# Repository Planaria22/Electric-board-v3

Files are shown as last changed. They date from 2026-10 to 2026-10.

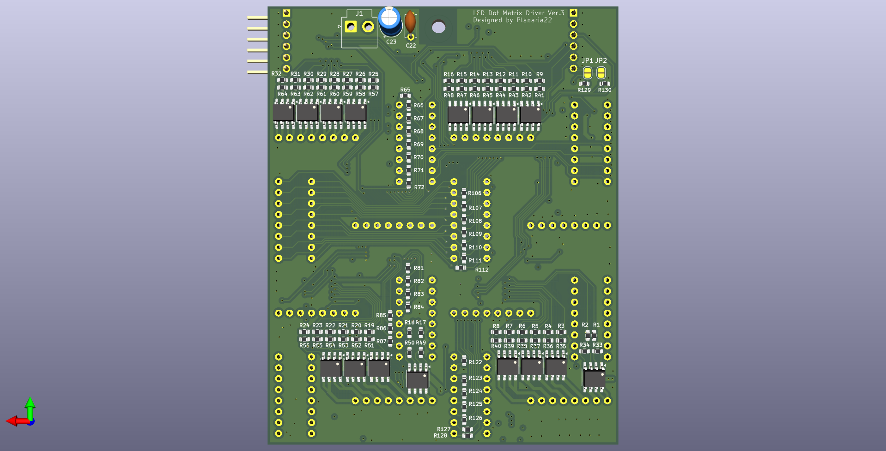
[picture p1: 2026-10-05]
img/dot_matrix_driver/electric_board_driver_v3_bottom.png

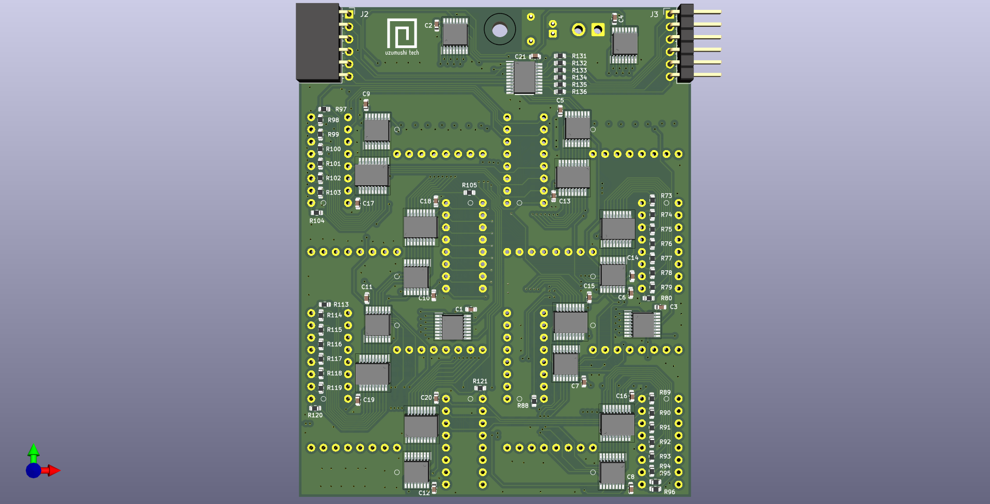
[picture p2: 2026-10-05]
img/dot_matrix_driver/electric_board_driver_v3_front.png

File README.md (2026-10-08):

# Electric-board-v3
2026年高専祭で展示する予定の電光掲示板です

# 概要
- MD1516C2-RG ドットマトリクスLED
  赤色と緑色のアノードコモン2色16×16LEDマトリクス。同時点灯を行うと赤緑橙の3色点灯が可能。このマトリクスをドライバ基板1枚に4個配置し、ドライバ基板を直列につなげることで32×128ドットの電光掲示板を作成する。
- ダイナミック点灯
  電流を流すアノード(行)を変え続けることで使用するピン数と電流を削減する。
- 制御
  カスケード接続された74HC595シフトレジスタを介してSPI通信で制御する。
  ドライバ基板のジャンパを繋げば輝度調整も技術的には可能

# ピンアサイン
ドライバ基板の端子アサイン
## 6pinピンヘッダ・ソケット
```
+---+---+=======+---+---+
| 1 | 2 | 3 | 4 | 5 | 6 |
+---+---+---+---+---+---+
```
※デフォルトでは基板側のOEピンはプルダウンされています。使用する場合はドライバ基板のJP1かJP2、あるいは両方のジャンパを短絡してください。
1. アノードデータ
2. 赤色LEDカソードデータ
3. 緑色LEDカソードデータ
4. 74HC595 シフトレジスタクロック(SRCLK)
5. 74HC595 ストレージレジスタークロック(RCLK)
6. 74HC595 アウトプットエネーブル(OE)

## 電源ピン
```
+=======+
| 1 | 2 |
+---+---+
```
※ドットマトリクス側が下
1. 5V電源+
2. GND電源-

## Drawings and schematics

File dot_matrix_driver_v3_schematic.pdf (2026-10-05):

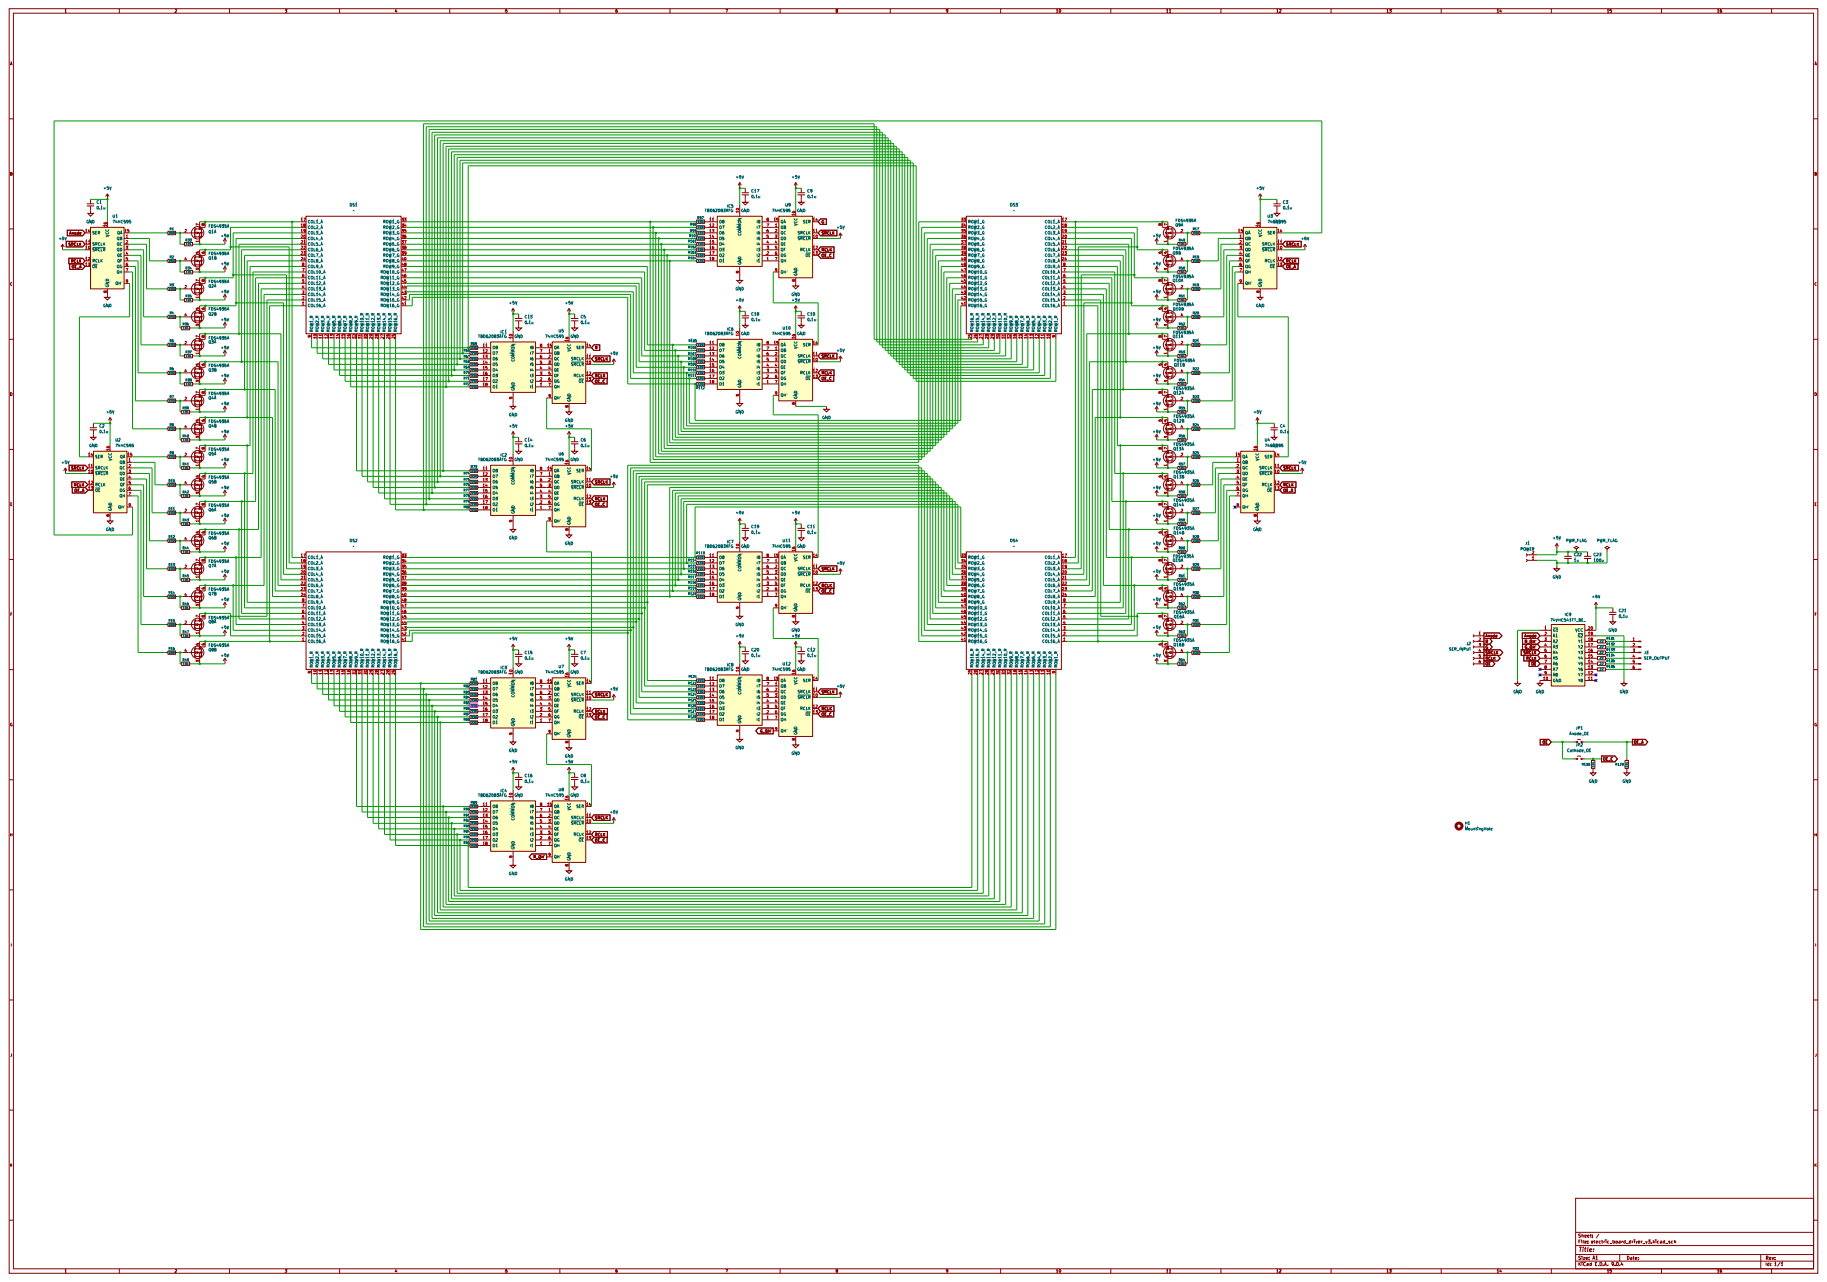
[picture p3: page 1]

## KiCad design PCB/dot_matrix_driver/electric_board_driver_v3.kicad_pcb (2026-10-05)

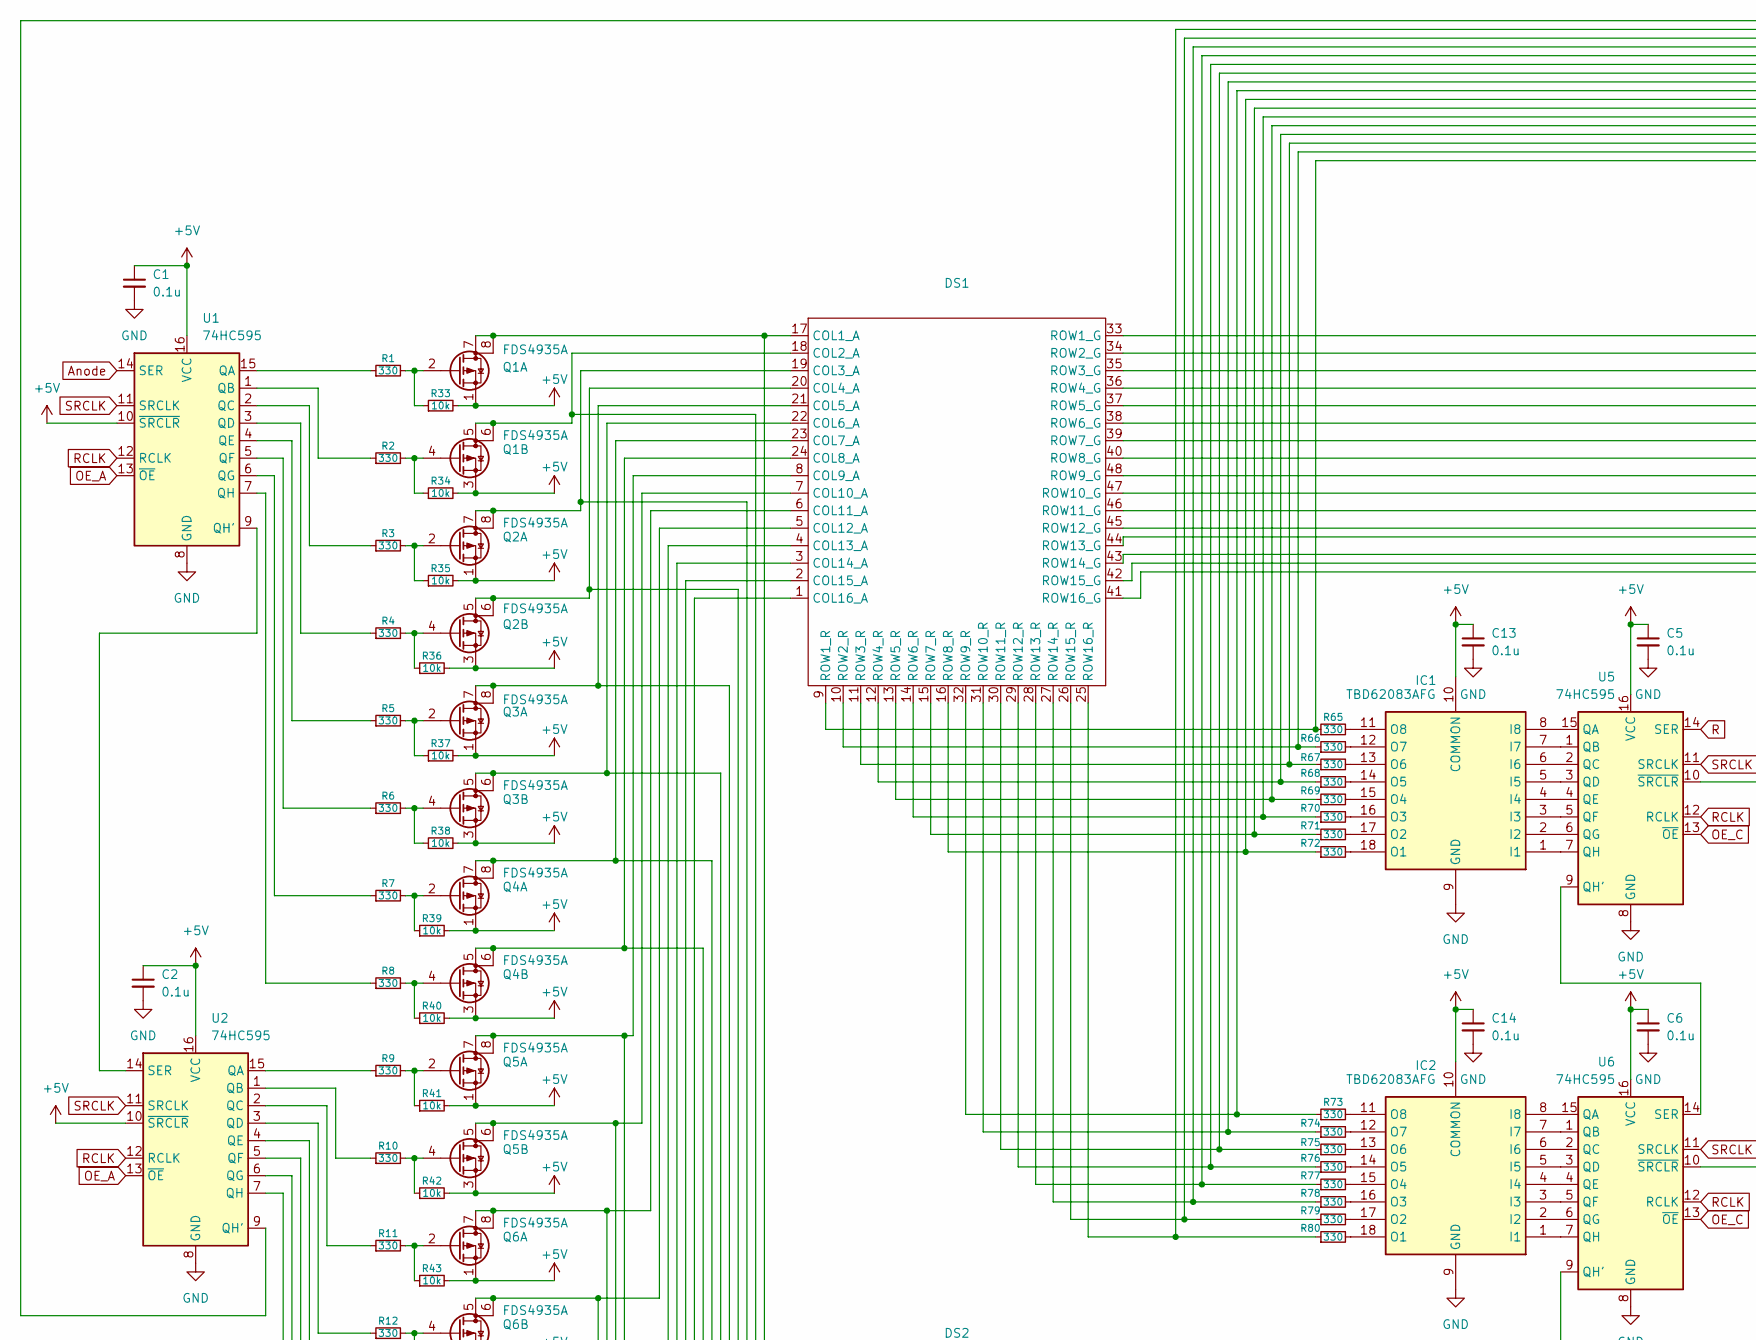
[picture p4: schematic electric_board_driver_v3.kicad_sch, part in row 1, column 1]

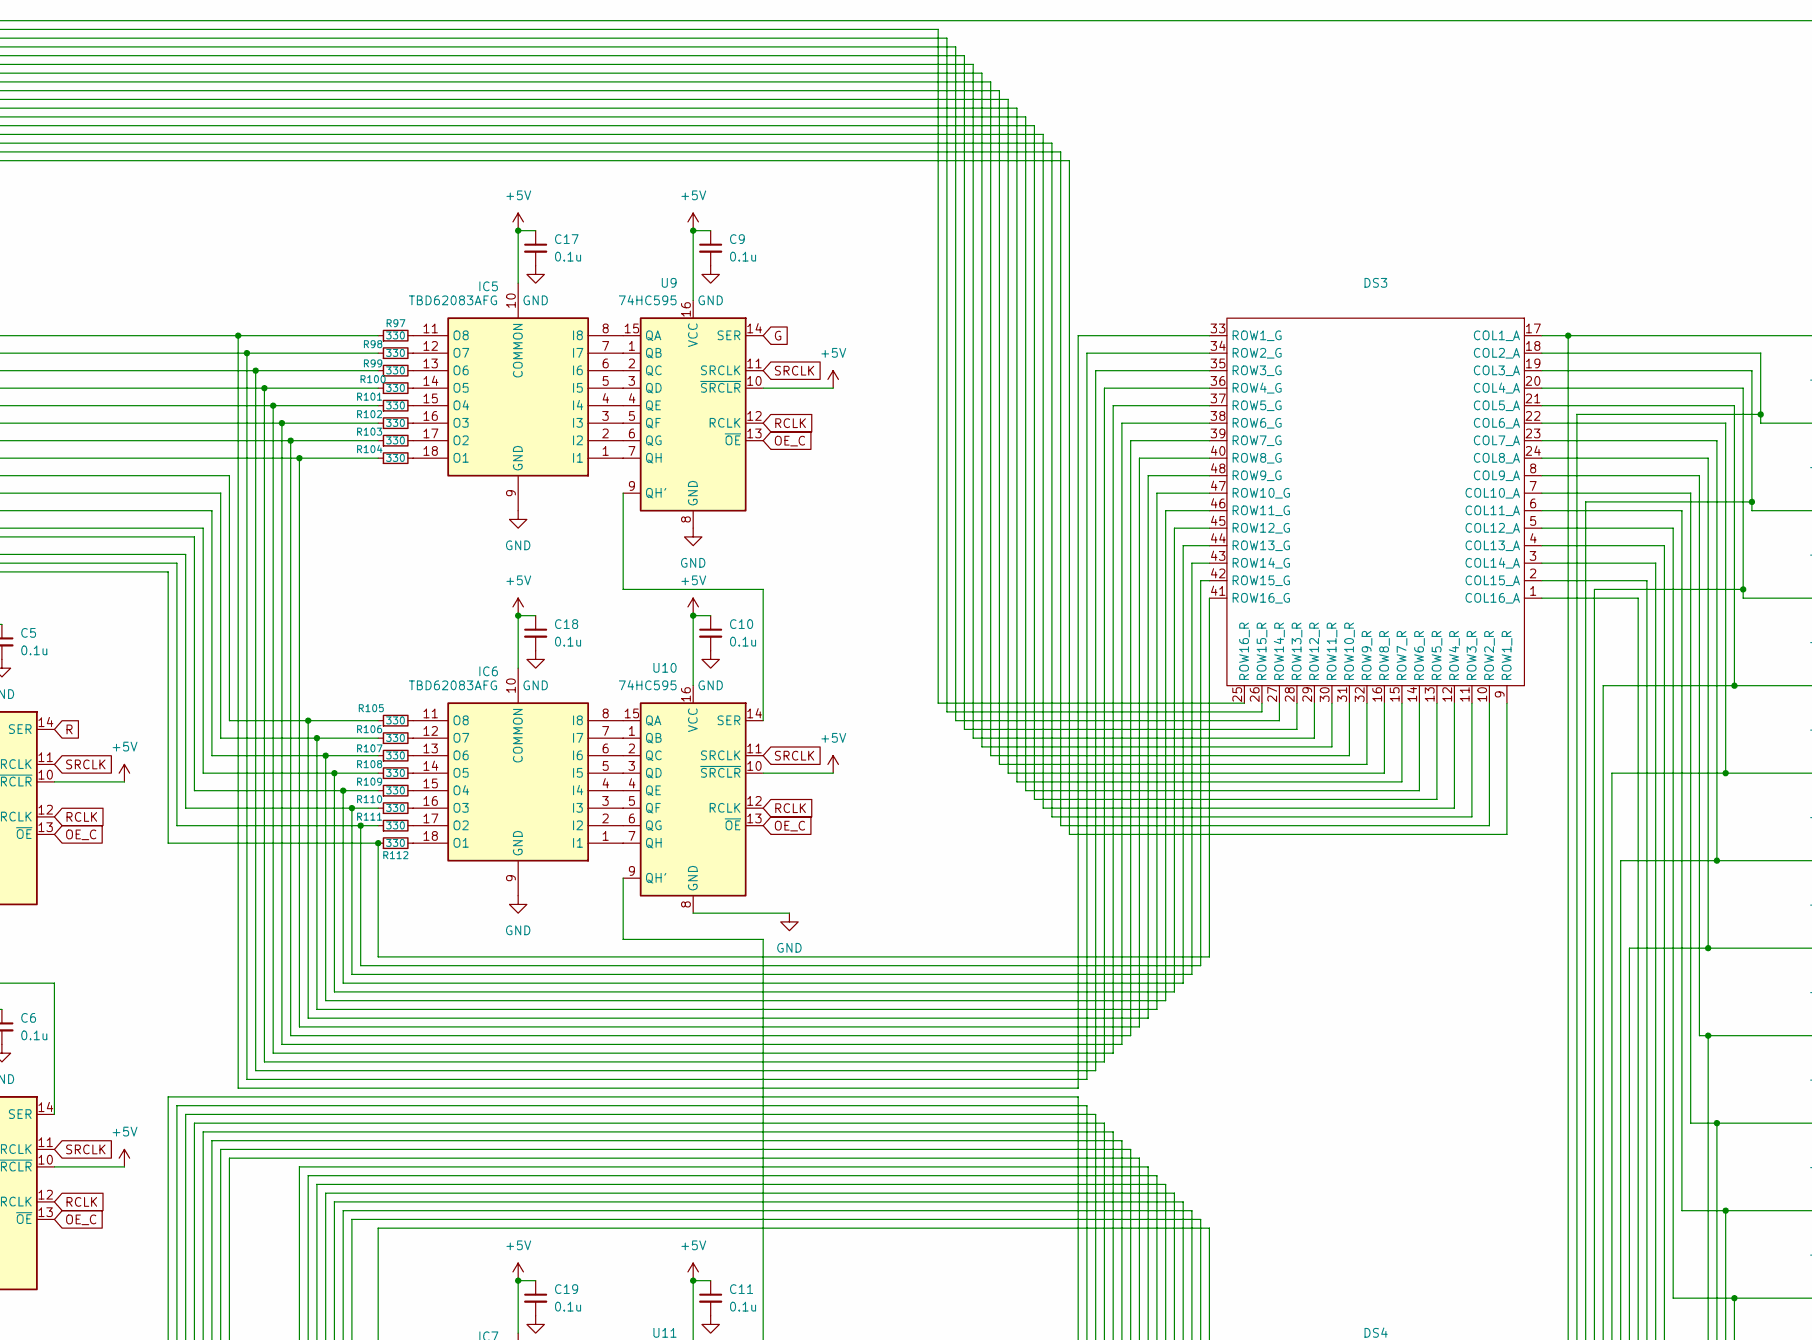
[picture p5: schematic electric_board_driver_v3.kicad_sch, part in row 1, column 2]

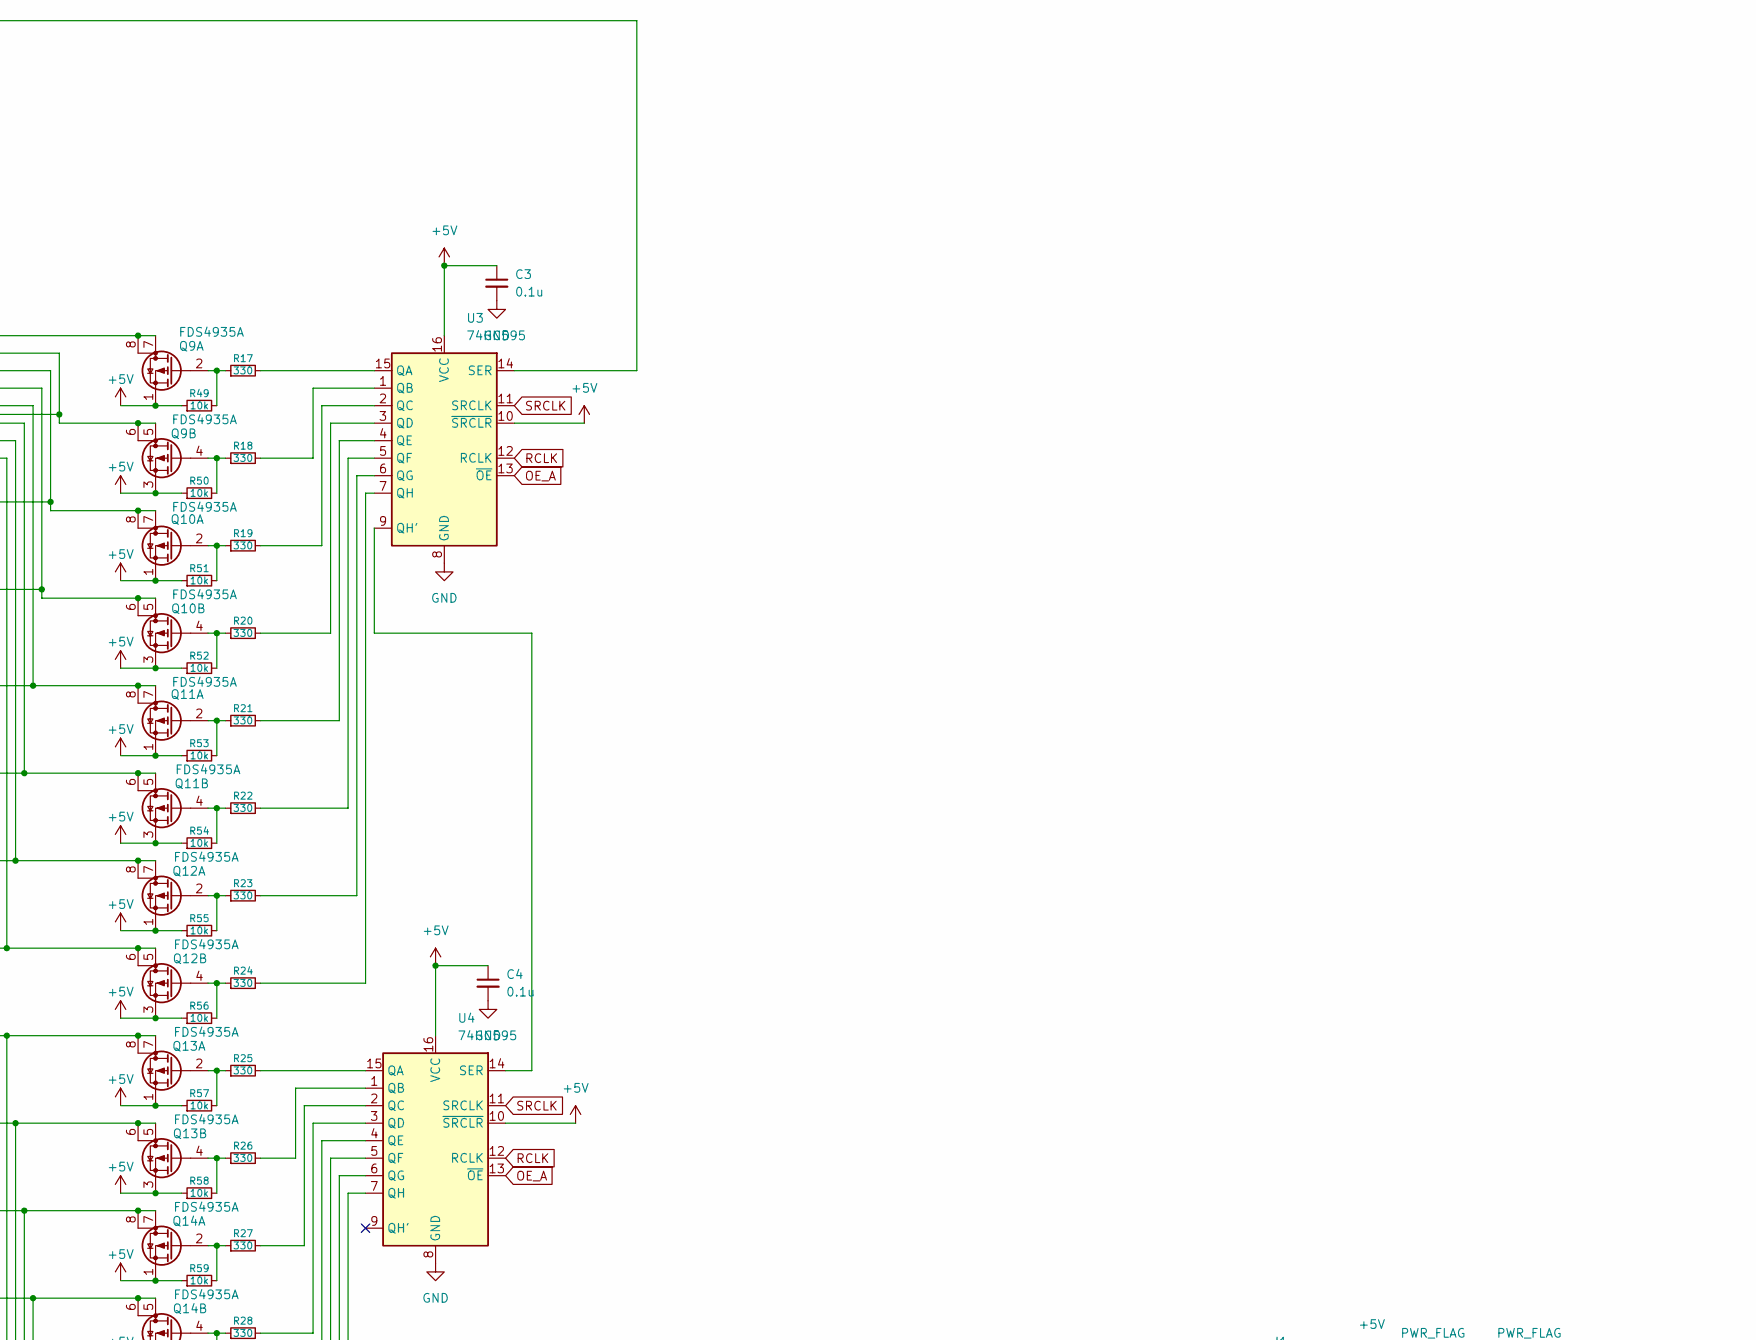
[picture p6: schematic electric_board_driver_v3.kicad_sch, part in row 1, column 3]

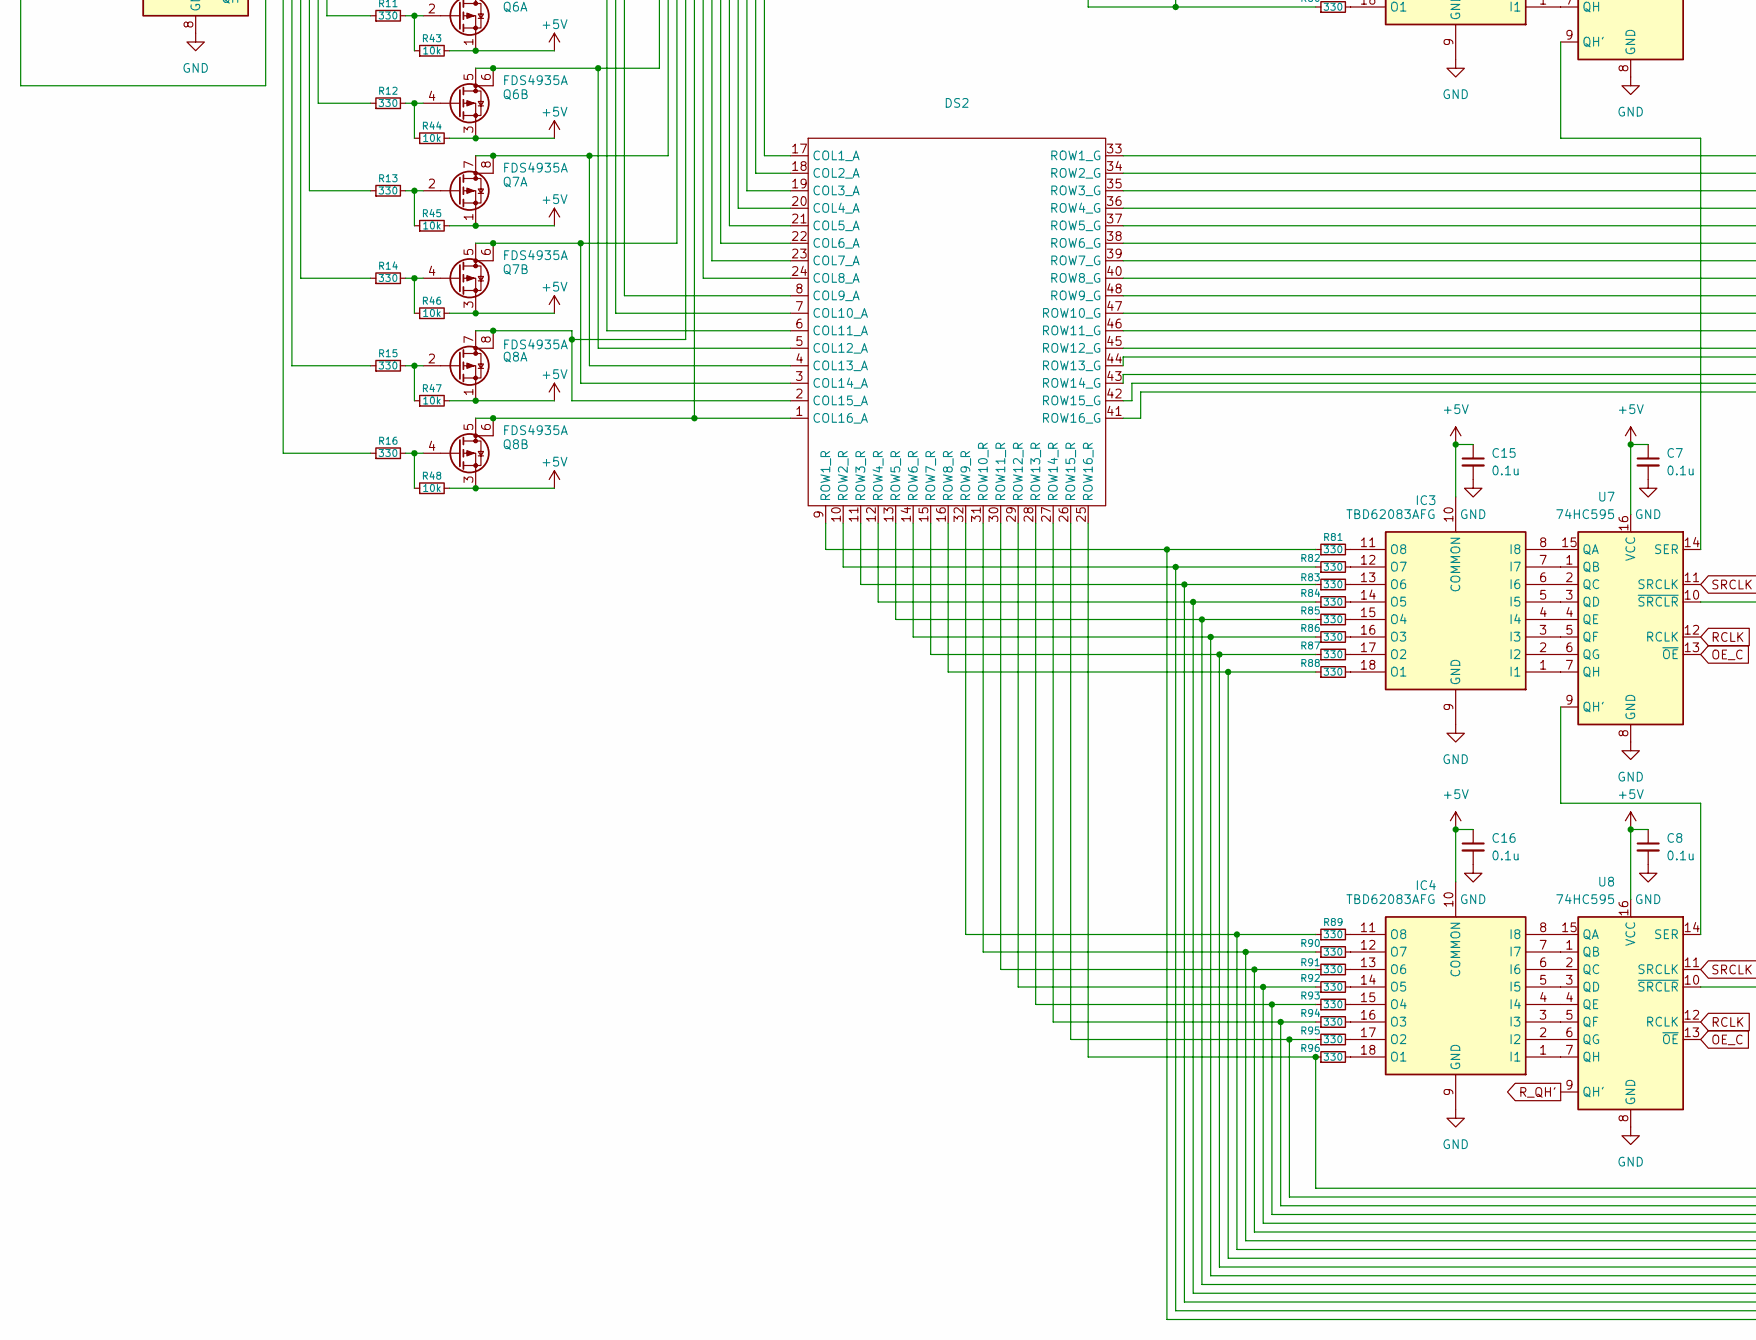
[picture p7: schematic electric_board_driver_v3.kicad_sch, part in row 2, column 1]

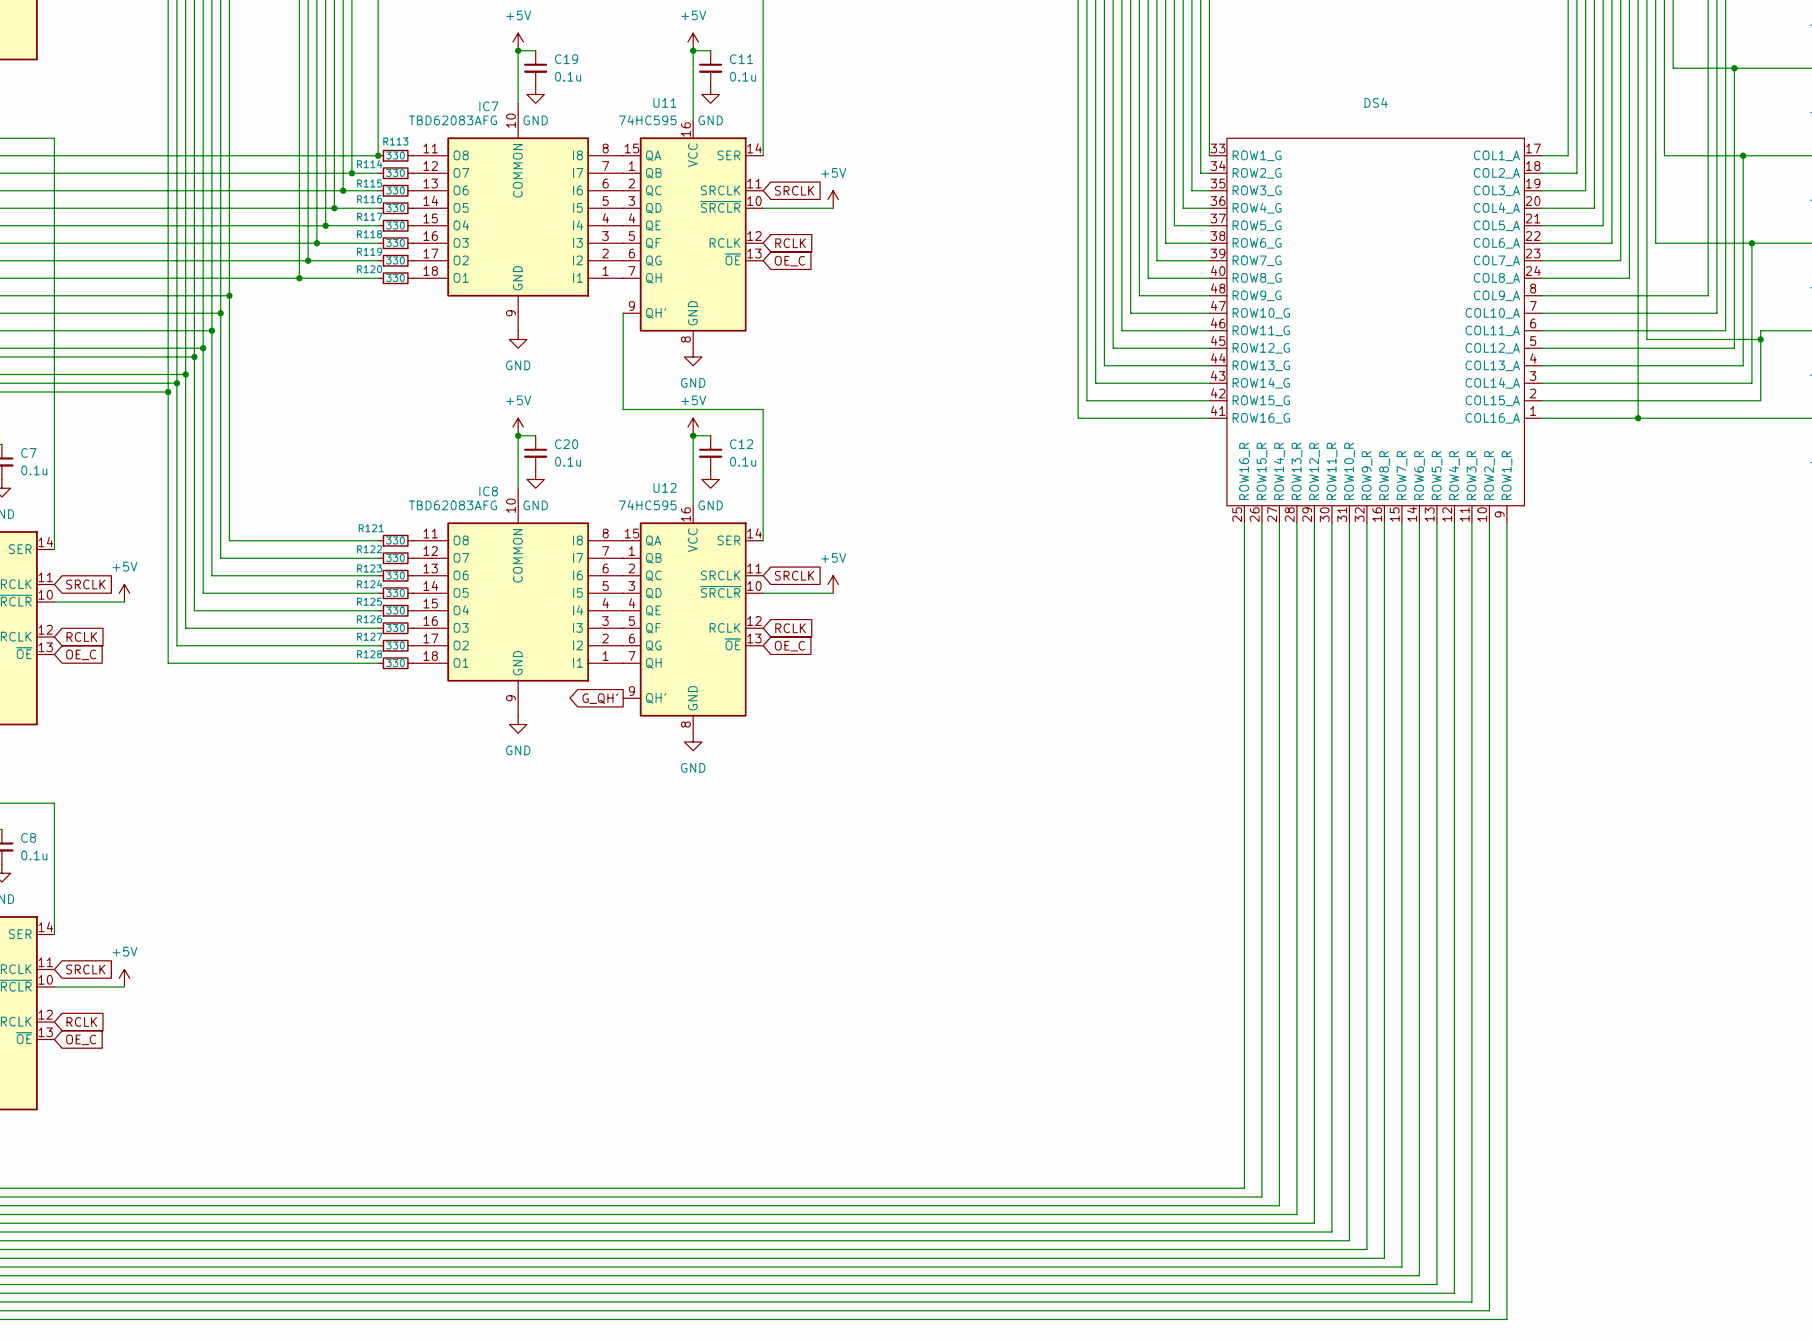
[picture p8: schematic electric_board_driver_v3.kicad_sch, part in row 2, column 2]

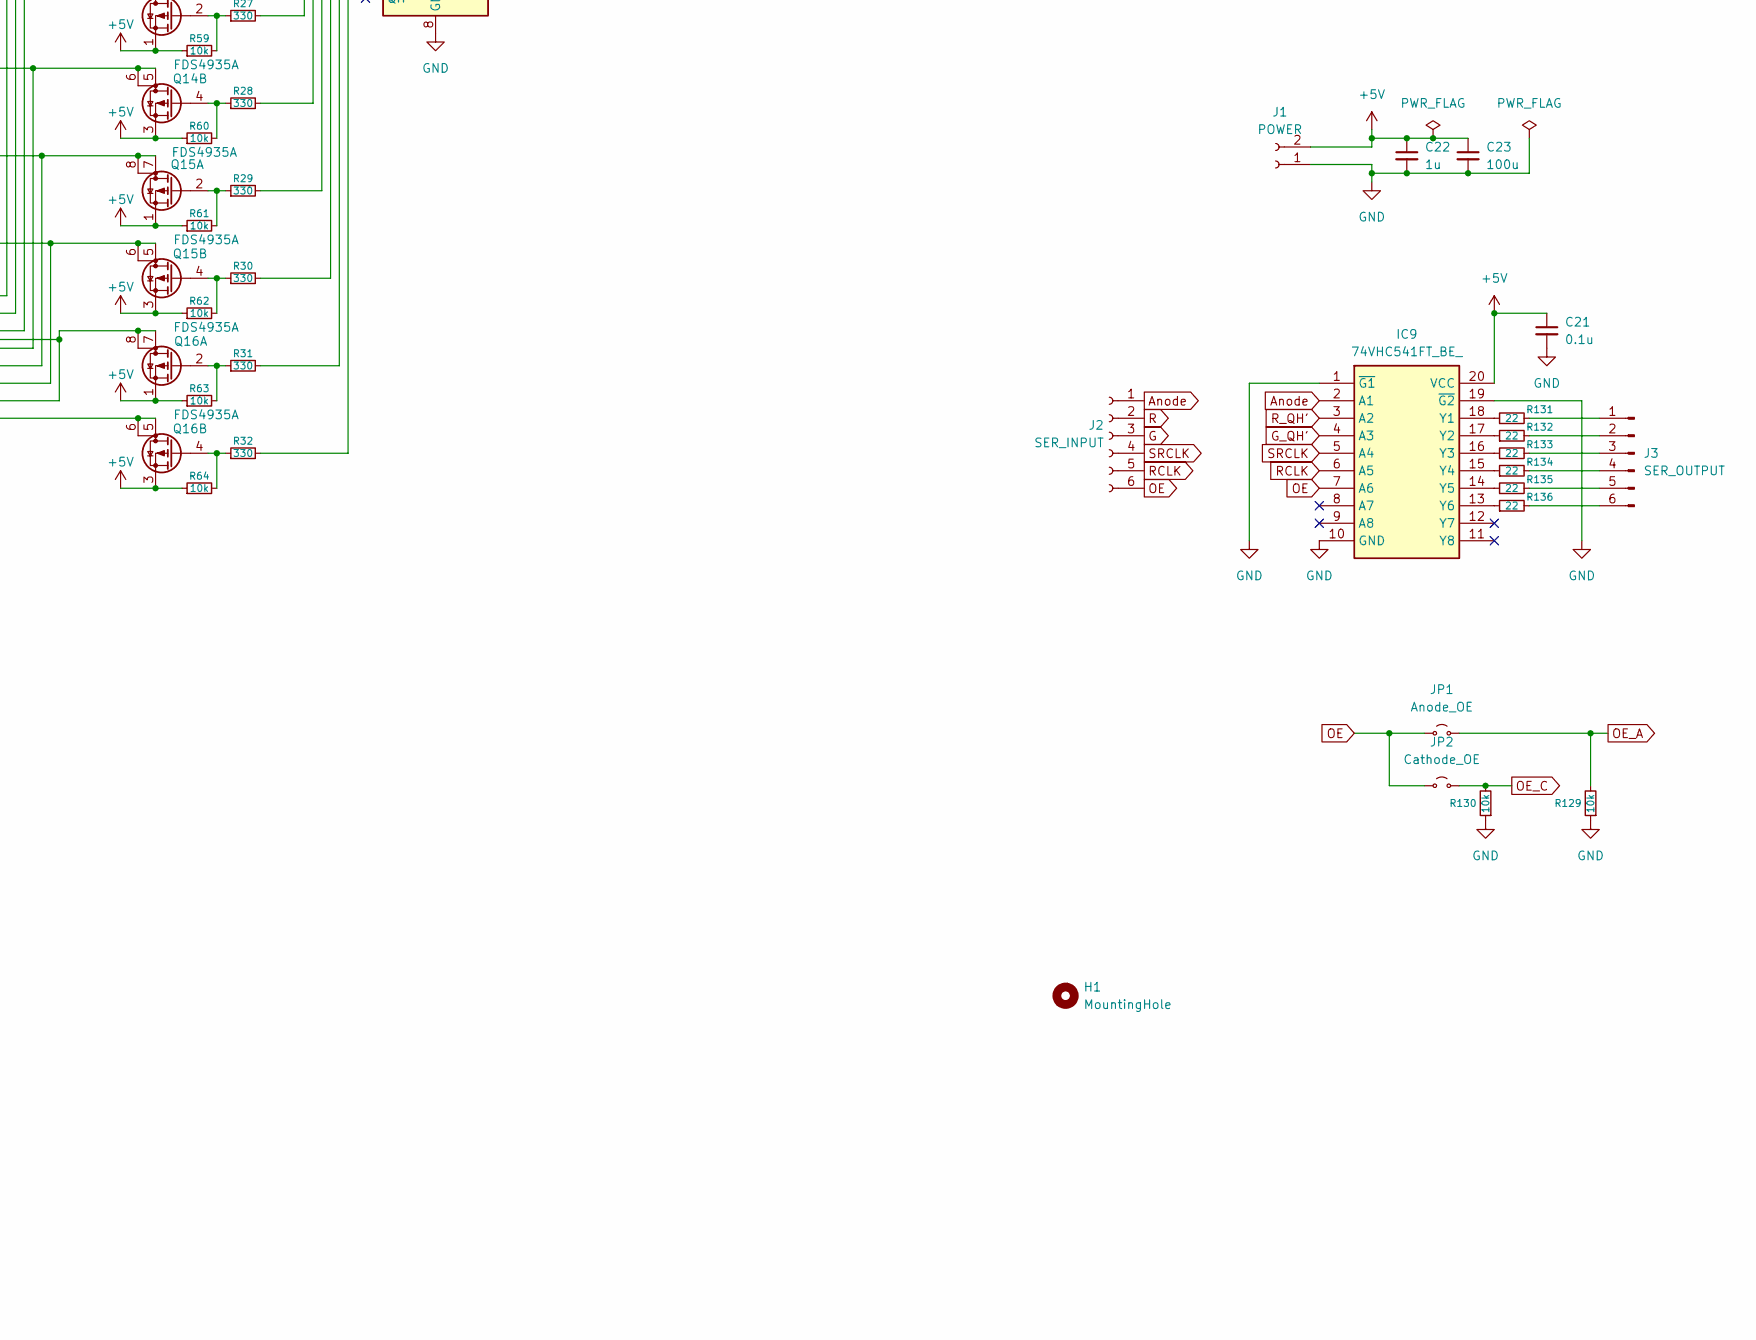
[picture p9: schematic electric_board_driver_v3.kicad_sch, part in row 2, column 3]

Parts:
C1, C2, C3, C4, C5, C6, C7, C8, C9, C10, C11, C12, C13, C14, C15, C16, C17, C18, C19, C20, C21: 0.1u; C_0603_1608Metric
C22: 1u; C_Disc_D5.0mm_W2.5mm_P5.00mm
C23: 100u; CP_Radial_D5.0mm_P2.00mm
DS1, DS2, DS3, DS4: MD1516
H1: MountingHole; MountingHole_3.2mm_M3
IC1, IC2, IC3, IC4, IC5, IC6, IC7, IC8: TBD62083AFG; TBD62083AFNG; Manufacturer_Part_Number TBD62083AFG; Mouser Part Number N/A
IC9: 74VHC541FT_BE_; 74VHC541FT(BE); Manufacturer_Part_Number 74VHC541FT(BE); Mouser Part Number 757-74VHC541FT(BE)
J1: POWER; JST_VH_B2P-VH_1x02_P3.96mm_Vertical
J2: SER_INPUT; PinSocket_1x06_P2.54mm_Horizontal
J3: SER_OUTPUT; PinHeader_1x06_P2.54mm_Horizontal
JP1: Anode_OE; SolderJumper-2_P1.3mm_Open_RoundedPad1.0x1.5mm
JP2: Cathode_OE; SolderJumper-2_P1.3mm_Open_RoundedPad1.0x1.5mm
Q1, Q2, Q3, Q4, Q5, Q6, Q7, Q8, Q9, Q10, Q11, Q12, Q13, Q14, Q15, Q16: FDS4935A; SOIC-8_3.9x4.9mm_P1.27mm
R1, R2, R3, R4, R5, R6, R7, R8, R9, R10, R11, R12, R13, R14, R15, R16, R17, R18, R19, R20, R21, R22, R23, R24, R25, R26, R27, R28, R29, R30, R31, R32, R65, R66, R67, R68, R69, R70, R71, R72, R73, R74, R75, R76, R77, R78, R79, R80, R81, R82, R83, R84, R85, R86, R87, R88, R89, R90, R91, R92, R93, R94, R95, R96, R97, R98, R99, R100, R101, R102, R103, R104, R105, R106, R107, R108, R109, R110, R111, R112, R113, R114, R115, R116, R117, R118, R119, R120, R121, R122, R123, R124, R125, R126, R127, R128: 330; R_0603_1608Metric
R33, R34, R35, R36, R37, R38, R39, R40, R41, R42, R43, R44, R45, R46, R47, R48, R49, R50, R51, R52, R53, R54, R55, R56, R57, R58, R59, R60, R61, R62, R63, R64, R129, R130: 10k; R_0603_1608Metric
R131, R132, R133, R134, R135, R136: 22; R_0603_1608Metric
U1, U2, U3, U4, U5, U6, U7, U8, U9, U10, U11, U12: 74HC595; MC74HC595ADTR2G

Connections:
+5V: C1.1, C2.1, C3.1, C4.1, C5.1, C6.1, C7.1, C8.1, C9.1, C10.1, C11.1, C12.1, C13.1, C14.1, C15.1, C16.1, C17.1, C18.1, C19.1, C20.1, C21.1, C22.1, C23.1, IC1.10 (COMMON), IC2.10 (COMMON), IC3.10 (COMMON), IC4.10 (COMMON), IC5.10 (COMMON), IC6.10 (COMMON), IC7.10 (COMMON), IC8.10 (COMMON), IC9.20 (VCC), J1.2, Q1.1 (S), Q1.3 (S), Q2.1 (S), Q2.3 (S), Q3.1 (S), Q3.3 (S), Q4.1 (S), Q4.3 (S), Q5.1 (S), Q5.3 (S), Q6.1 (S), Q6.3 (S), Q7.1 (S), Q7.3 (S), Q8.1 (S), Q8.3 (S), Q9.1 (S), Q9.3 (S), Q10.1 (S), Q10.3 (S), Q11.1 (S), Q11.3 (S), Q12.1 (S), Q12.3 (S), Q13.1 (S), Q13.3 (S), Q14.1 (S), Q14.3 (S), Q15.1 (S), Q15.3 (S), Q16.1 (S), Q16.3 (S), R33.2, R34.2, R35.2, R36.2, R37.2, R38.2, R39.2, R40.2, R41.2, R42.2, R43.2, R44.2, R45.2, R46.2, R47.2, R48.2, R49.1, R50.1, R51.1, R52.1, R53.1, R54.1, R55.1, R56.1, R57.1, R58.1, R59.1, R60.1, R61.1, R62.1, R63.1, R64.1, U1.10 (~SRCLR), U1.16 (VCC), U2.10 (~SRCLR), U2.16 (VCC), U3.10 (~SRCLR), U3.16 (VCC), U4.10 (~SRCLR), U4.16 (VCC), U5.10 (~SRCLR), U5.16 (VCC), U6.10 (~SRCLR), U6.16 (VCC), U7.10 (~SRCLR), U7.16 (VCC), U8.10 (~SRCLR), U8.16 (VCC), U9.10 (~SRCLR), U9.16 (VCC), U10.10 (~SRCLR), U10.16 (VCC), U11.10 (~SRCLR), U11.16 (VCC), U12.10 (~SRCLR), U12.16 (VCC)
Anode: IC9.2 (A1), J2.1, U1.14 (SER)
G: J2.3, U9.14 (SER)
GND: C1.2, C2.2, C3.2, C4.2, C5.2, C6.2, C7.2, C8.2, C9.2, C10.2, C11.2, C12.2, C13.2, C14.2, C15.2, C16.2, C17.2, C18.2, C19.2, C20.2, C21.2, C22.2, C23.2, IC1.9 (GND), IC2.9 (GND), IC3.9 (GND), IC4.9 (GND), IC5.9 (GND), IC6.9 (GND), IC7.9 (GND), IC8.9 (GND), IC9.1 (~G1), IC9.10 (GND), IC9.19 (~G2), J1.1, R129.1, R130.1, U1.8 (GND), U2.8 (GND), U3.8 (GND), U4.8 (GND), U5.8 (GND), U6.8 (GND), U7.8 (GND), U8.8 (GND), U9.8 (GND), U10.8 (GND), U11.8 (GND), U12.8 (GND)
G_QH': IC9.4 (A3), U12.9 (QH')
unnamed: DS1.17 (COL1_A), DS2.17 (COL1_A), Q1.7 (D), Q1.8 (D)
unnamed: DS1.18 (COL2_A), DS2.18 (COL2_A), Q1.5 (D), Q1.6 (D)
unnamed: DS1.19 (COL3_A), DS2.19 (COL3_A), Q2.7 (D), Q2.8 (D)
unnamed: DS1.20 (COL4_A), DS2.20 (COL4_A), Q2.5 (D), Q2.6 (D)
unnamed: DS1.21 (COL5_A), DS2.21 (COL5_A), Q3.7 (D), Q3.8 (D)
unnamed: DS1.22 (COL6_A), DS2.22 (COL6_A), Q3.5 (D), Q3.6 (D)
unnamed: DS1.23 (COL7_A), DS2.23 (COL7_A), Q4.7 (D), Q4.8 (D)
unnamed: DS1.24 (COL8_A), DS2.24 (COL8_A), Q4.5 (D), Q4.6 (D)
unnamed: DS1.8 (COL9_A), DS2.8 (COL9_A), Q5.7 (D), Q5.8 (D)
unnamed: DS1.7 (COL10_A), DS2.7 (COL10_A), Q5.5 (D), Q5.6 (D)
unnamed: DS1.6 (COL11_A), DS2.6 (COL11_A), Q6.7 (D), Q6.8 (D)
unnamed: DS1.5 (COL12_A), DS2.5 (COL12_A), Q6.5 (D), Q6.6 (D)
unnamed: DS1.4 (COL13_A), DS2.4 (COL13_A), Q7.7 (D), Q7.8 (D)
unnamed: DS1.3 (COL14_A), DS2.3 (COL14_A), Q7.5 (D), Q7.6 (D)
unnamed: DS1.2 (COL15_A), DS2.2 (COL15_A), Q8.7 (D), Q8.8 (D)
unnamed: DS1.1 (COL16_A), DS2.1 (COL16_A), Q8.5 (D), Q8.6 (D)
unnamed: DS1.33 (ROW1_G), DS3.33 (ROW1_G), R97.1
unnamed: DS1.9 (ROW1_R), DS3.9 (ROW1_R), R65.1
unnamed: DS1.34 (ROW2_G), DS3.34 (ROW2_G), R98.1
unnamed: DS1.10 (ROW2_R), DS3.10 (ROW2_R), R66.1
unnamed: DS1.35 (ROW3_G), DS3.35 (ROW3_G), R99.1
unnamed: DS1.11 (ROW3_R), DS3.11 (ROW3_R), R67.1
unnamed: DS1.36 (ROW4_G), DS3.36 (ROW4_G), R100.1
unnamed: DS1.12 (ROW4_R), DS3.12 (ROW4_R), R68.1
unnamed: DS1.37 (ROW5_G), DS3.37 (ROW5_G), R101.1
unnamed: DS1.13 (ROW5_R), DS3.13 (ROW5_R), R69.1
unnamed: DS1.38 (ROW6_G), DS3.38 (ROW6_G), R102.1
unnamed: DS1.14 (ROW6_R), DS3.14 (ROW6_R), R70.1
unnamed: DS1.39 (ROW7_G), DS3.39 (ROW7_G), R103.1
unnamed: DS1.15 (ROW7_R), DS3.15 (ROW7_R), R71.1
unnamed: DS1.40 (ROW8_G), DS3.40 (ROW8_G), R104.1
unnamed: DS1.16 (ROW8_R), DS3.16 (ROW8_R), R72.1
unnamed: DS1.48 (ROW9_G), DS3.48 (ROW9_G), R105.1
unnamed: DS1.32 (ROW9_R), DS3.32 (ROW9_R), R73.1
unnamed: DS1.47 (ROW10_G), DS3.47 (ROW10_G), R106.1
unnamed: DS1.31 (ROW10_R), DS3.31 (ROW10_R), R74.1
unnamed: DS1.46 (ROW11_G), DS3.46 (ROW11_G), R107.1
unnamed: DS1.30 (ROW11_R), DS3.30 (ROW11_R), R75.1
unnamed: DS1.45 (ROW12_G), DS3.45 (ROW12_G), R108.1
unnamed: DS1.29 (ROW12_R), DS3.29 (ROW12_R), R76.1
unnamed: DS1.44 (ROW13_G), DS3.44 (ROW13_G), R109.1
unnamed: DS1.28 (ROW13_R), DS3.28 (ROW13_R), R77.1
unnamed: DS1.43 (ROW14_G), DS3.43 (ROW14_G), R110.1
unnamed: DS1.27 (ROW14_R), DS3.27 (ROW14_R), R78.1
unnamed: DS1.42 (ROW15_G), DS3.42 (ROW15_G), R111.1
unnamed: DS1.26 (ROW15_R), DS3.26 (ROW15_R), R79.1
unnamed: DS1.41 (ROW16_G), DS3.41 (ROW16_G), R112.1
unnamed: DS1.25 (ROW16_R), DS3.25 (ROW16_R), R80.1
unnamed: DS2.33 (ROW1_G), DS4.33 (ROW1_G), R113.1
unnamed: DS2.9 (ROW1_R), DS4.9 (ROW1_R), R81.1
unnamed: DS2.34 (ROW2_G), DS4.34 (ROW2_G), R114.1
unnamed: DS2.10 (ROW2_R), DS4.10 (ROW2_R), R82.1
unnamed: DS2.35 (ROW3_G), DS4.35 (ROW3_G), R115.1
unnamed: DS2.11 (ROW3_R), DS4.11 (ROW3_R), R83.1
unnamed: DS2.36 (ROW4_G), DS4.36 (ROW4_G), R116.1
unnamed: DS2.12 (ROW4_R), DS4.12 (ROW4_R), R84.1
unnamed: DS2.37 (ROW5_G), DS4.37 (ROW5_G), R117.1
unnamed: DS2.13 (ROW5_R), DS4.13 (ROW5_R), R85.1
unnamed: DS2.38 (ROW6_G), DS4.38 (ROW6_G), R118.1
unnamed: DS2.14 (ROW6_R), DS4.14 (ROW6_R), R86.1
unnamed: DS2.39 (ROW7_G), DS4.39 (ROW7_G), R119.1
unnamed: DS2.15 (ROW7_R), DS4.15 (ROW7_R), R87.1
unnamed: DS2.40 (ROW8_G), DS4.40 (ROW8_G), R120.1
unnamed: DS2.16 (ROW8_R), DS4.16 (ROW8_R), R88.1
unnamed: DS2.48 (ROW9_G), DS4.48 (ROW9_G), R121.1
unnamed: DS2.32 (ROW9_R), DS4.32 (ROW9_R), R89.1
unnamed: DS2.47 (ROW10_G), DS4.47 (ROW10_G), R122.1
unnamed: DS2.31 (ROW10_R), DS4.31 (ROW10_R), R90.1
unnamed: DS2.46 (ROW11_G), DS4.46 (ROW11_G), R123.1
unnamed: DS2.30 (ROW11_R), DS4.30 (ROW11_R), R91.1
unnamed: DS2.45 (ROW12_G), DS4.45 (ROW12_G), R124.1
unnamed: DS2.29 (ROW12_R), DS4.29 (ROW12_R), R92.1
unnamed: DS2.44 (ROW13_G), DS4.44 (ROW13_G), R125.1
unnamed: DS2.28 (ROW13_R), DS4.28 (ROW13_R), R93.1
unnamed: DS2.43 (ROW14_G), DS4.43 (ROW14_G), R126.1
unnamed: DS2.27 (ROW14_R), DS4.27 (ROW14_R), R94.1
unnamed: DS2.42 (ROW15_G), DS4.42 (ROW15_G), R127.1
unnamed: DS2.26 (ROW15_R), DS4.26 (ROW15_R), R95.1
unnamed: DS2.41 (ROW16_G), DS4.41 (ROW16_G), R128.1
unnamed: DS2.25 (ROW16_R), DS4.25 (ROW16_R), R96.1
unnamed: DS3.17 (COL1_A), DS4.17 (COL1_A), Q9.7 (D), Q9.8 (D)
unnamed: DS3.18 (COL2_A), DS4.18 (COL2_A), Q9.5 (D), Q9.6 (D)
unnamed: DS3.19 (COL3_A), DS4.19 (COL3_A), Q10.7 (D), Q10.8 (D)
unnamed: DS3.20 (COL4_A), DS4.20 (COL4_A), Q10.5 (D), Q10.6 (D)
unnamed: DS3.21 (COL5_A), DS4.21 (COL5_A), Q11.7 (D), Q11.8 (D)
unnamed: DS3.22 (COL6_A), DS4.22 (COL6_A), Q11.5 (D), Q11.6 (D)
unnamed: DS3.23 (COL7_A), DS4.23 (COL7_A), Q12.7 (D), Q12.8 (D)
unnamed: DS3.24 (COL8_A), DS4.24 (COL8_A), Q12.5 (D), Q12.6 (D)
unnamed: DS3.8 (COL9_A), DS4.8 (COL9_A), Q13.7 (D), Q13.8 (D)
unnamed: DS3.7 (COL10_A), DS4.7 (COL10_A), Q13.5 (D), Q13.6 (D)
unnamed: DS3.6 (COL11_A), DS4.6 (COL11_A), Q14.7 (D), Q14.8 (D)
unnamed: DS3.5 (COL12_A), DS4.5 (COL12_A), Q14.5 (D), Q14.6 (D)
unnamed: DS3.4 (COL13_A), DS4.4 (COL13_A), Q15.7 (D), Q15.8 (D)
unnamed: DS3.3 (COL14_A), DS4.3 (COL14_A), Q15.5 (D), Q15.6 (D)
unnamed: DS3.2 (COL15_A), DS4.2 (COL15_A), Q16.7 (D), Q16.8 (D)
unnamed: DS3.1 (COL16_A), DS4.1 (COL16_A), Q16.5 (D), Q16.6 (D)
unnamed: IC1.1 (I1), U5.7 (QH)
unnamed: IC1.2 (I2), U5.6 (QG)
unnamed: IC1.3 (I3), U5.5 (QF)
unnamed: IC1.4 (I4), U5.4 (QE)
unnamed: IC1.5 (I5), U5.3 (QD)
unnamed: IC1.6 (I6), U5.2 (QC)
unnamed: IC1.7 (I7), U5.1 (QB)
unnamed: IC1.8 (I8), U5.15 (QA)
unnamed: IC1.18 (O1), R72.2
unnamed: IC1.17 (O2), R71.2
unnamed: IC1.16 (O3), R70.2
unnamed: IC1.15 (O4), R69.2
unnamed: IC1.14 (O5), R68.2
unnamed: IC1.13 (O6), R67.2
unnamed: IC1.12 (O7), R66.2
unnamed: IC1.11 (O8), R65.2
unnamed: IC2.1 (I1), U6.7 (QH)
unnamed: IC2.2 (I2), U6.6 (QG)
unnamed: IC2.3 (I3), U6.5 (QF)
unnamed: IC2.4 (I4), U6.4 (QE)
unnamed: IC2.5 (I5), U6.3 (QD)
unnamed: IC2.6 (I6), U6.2 (QC)
unnamed: IC2.7 (I7), U6.1 (QB)
unnamed: IC2.8 (I8), U6.15 (QA)
unnamed: IC2.18 (O1), R80.2
unnamed: IC2.17 (O2), R79.2
unnamed: IC2.16 (O3), R78.2
unnamed: IC2.15 (O4), R77.2
unnamed: IC2.14 (O5), R76.2
unnamed: IC2.13 (O6), R75.2
unnamed: IC2.12 (O7), R74.2
unnamed: IC2.11 (O8), R73.2
unnamed: IC3.1 (I1), U7.7 (QH)
unnamed: IC3.2 (I2), U7.6 (QG)
unnamed: IC3.3 (I3), U7.5 (QF)
unnamed: IC3.4 (I4), U7.4 (QE)
unnamed: IC3.5 (I5), U7.3 (QD)
unnamed: IC3.6 (I6), U7.2 (QC)
unnamed: IC3.7 (I7), U7.1 (QB)
unnamed: IC3.8 (I8), U7.15 (QA)
unnamed: IC3.18 (O1), R88.2
unnamed: IC3.17 (O2), R87.2
unnamed: IC3.16 (O3), R86.2
unnamed: IC3.15 (O4), R85.2
unnamed: IC3.14 (O5), R84.2
unnamed: IC3.13 (O6), R83.2
unnamed: IC3.12 (O7), R82.2
unnamed: IC3.11 (O8), R81.2
unnamed: IC4.1 (I1), U8.7 (QH)
unnamed: IC4.2 (I2), U8.6 (QG)
unnamed: IC4.3 (I3), U8.5 (QF)
unnamed: IC4.4 (I4), U8.4 (QE)
unnamed: IC4.5 (I5), U8.3 (QD)
unnamed: IC4.6 (I6), U8.2 (QC)
unnamed: IC4.7 (I7), U8.1 (QB)
unnamed: IC4.8 (I8), U8.15 (QA)
unnamed: IC4.18 (O1), R96.2
unnamed: IC4.17 (O2), R95.2
unnamed: IC4.16 (O3), R94.2
unnamed: IC4.15 (O4), R93.2
unnamed: IC4.14 (O5), R92.2
unnamed: IC4.13 (O6), R91.2
unnamed: IC4.12 (O7), R90.2
unnamed: IC4.11 (O8), R89.2
unnamed: IC5.1 (I1), U9.7 (QH)
unnamed: IC5.2 (I2), U9.6 (QG)
unnamed: IC5.3 (I3), U9.5 (QF)
unnamed: IC5.4 (I4), U9.4 (QE)
unnamed: IC5.5 (I5), U9.3 (QD)
unnamed: IC5.6 (I6), U9.2 (QC)
unnamed: IC5.7 (I7), U9.1 (QB)
unnamed: IC5.8 (I8), U9.15 (QA)
unnamed: IC5.18 (O1), R104.2
unnamed: IC5.17 (O2), R103.2
unnamed: IC5.16 (O3), R102.2
unnamed: IC5.15 (O4), R101.2
unnamed: IC5.14 (O5), R100.2
unnamed: IC5.13 (O6), R99.2
unnamed: IC5.12 (O7), R98.2
unnamed: IC5.11 (O8), R97.2
unnamed: IC6.1 (I1), U10.7 (QH)
unnamed: IC6.2 (I2), U10.6 (QG)
unnamed: IC6.3 (I3), U10.5 (QF)
unnamed: IC6.4 (I4), U10.4 (QE)
unnamed: IC6.5 (I5), U10.3 (QD)
unnamed: IC6.6 (I6), U10.2 (QC)
unnamed: IC6.7 (I7), U10.1 (QB)
unnamed: IC6.8 (I8), U10.15 (QA)
unnamed: IC6.18 (O1), R112.2
unnamed: IC6.17 (O2), R111.2
unnamed: IC6.16 (O3), R110.2
unnamed: IC6.15 (O4), R109.2
unnamed: IC6.14 (O5), R108.2
unnamed: IC6.13 (O6), R107.2
unnamed: IC6.12 (O7), R106.2
unnamed: IC6.11 (O8), R105.2
unnamed: IC7.1 (I1), U11.7 (QH)
unnamed: IC7.2 (I2), U11.6 (QG)
unnamed: IC7.3 (I3), U11.5 (QF)
unnamed: IC7.4 (I4), U11.4 (QE)
unnamed: IC7.5 (I5), U11.3 (QD)
unnamed: IC7.6 (I6), U11.2 (QC)
unnamed: IC7.7 (I7), U11.1 (QB)
unnamed: IC7.8 (I8), U11.15 (QA)
unnamed: IC7.18 (O1), R120.2
unnamed: IC7.17 (O2), R119.2
unnamed: IC7.16 (O3), R118.2
unnamed: IC7.15 (O4), R117.2
unnamed: IC7.14 (O5), R116.2
unnamed: IC7.13 (O6), R115.2
unnamed: IC7.12 (O7), R114.2
unnamed: IC7.11 (O8), R113.2
unnamed: IC8.1 (I1), U12.7 (QH)
unnamed: IC8.2 (I2), U12.6 (QG)
unnamed: IC8.3 (I3), U12.5 (QF)
unnamed: IC8.4 (I4), U12.4 (QE)
unnamed: IC8.5 (I5), U12.3 (QD)
unnamed: IC8.6 (I6), U12.2 (QC)
unnamed: IC8.7 (I7), U12.1 (QB)
unnamed: IC8.8 (I8), U12.15 (QA)
unnamed: IC8.18 (O1), R128.2
unnamed: IC8.17 (O2), R127.2
unnamed: IC8.16 (O3), R126.2
unnamed: IC8.15 (O4), R125.2
unnamed: IC8.14 (O5), R124.2
unnamed: IC8.13 (O6), R123.2
unnamed: IC8.12 (O7), R122.2
unnamed: IC8.11 (O8), R121.2
unnamed: IC9.18 (Y1), R131.1
unnamed: IC9.17 (Y2), R132.1
unnamed: IC9.16 (Y3), R133.1
unnamed: IC9.15 (Y4), R134.1
unnamed: IC9.14 (Y5), R135.1
unnamed: IC9.13 (Y6), R136.1
unnamed: J3.1, R131.2
unnamed: J3.2, R132.2
unnamed: J3.3, R133.2
unnamed: J3.4, R134.2
unnamed: J3.5, R135.2
unnamed: J3.6, R136.2
unnamed: Q1.2 (G), R1.2, R33.1
unnamed: Q1.4 (G), R2.2, R34.1
unnamed: Q2.2 (G), R3.2, R35.1
unnamed: Q2.4 (G), R4.2, R36.1
unnamed: Q3.2 (G), R5.2, R37.1
unnamed: Q3.4 (G), R6.2, R38.1
unnamed: Q4.2 (G), R7.2, R39.1
unnamed: Q4.4 (G), R8.2, R40.1
unnamed: Q5.2 (G), R9.2, R41.1
unnamed: Q5.4 (G), R10.2, R42.1
unnamed: Q6.2 (G), R11.2, R43.1
unnamed: Q6.4 (G), R12.2, R44.1
unnamed: Q7.2 (G), R13.2, R45.1
unnamed: Q7.4 (G), R14.2, R46.1
unnamed: Q8.2 (G), R15.2, R47.1
unnamed: Q8.4 (G), R16.2, R48.1
unnamed: Q9.2 (G), R17.1, R49.2
unnamed: Q9.4 (G), R18.1, R50.2
unnamed: Q10.2 (G), R19.1, R51.2
unnamed: Q10.4 (G), R20.1, R52.2
unnamed: Q11.2 (G), R21.1, R53.2
unnamed: Q11.4 (G), R22.1, R54.2
unnamed: Q12.2 (G), R23.1, R55.2
unnamed: Q12.4 (G), R24.1, R56.2
unnamed: Q13.2 (G), R25.1, R57.2
unnamed: Q13.4 (G), R26.1, R58.2
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

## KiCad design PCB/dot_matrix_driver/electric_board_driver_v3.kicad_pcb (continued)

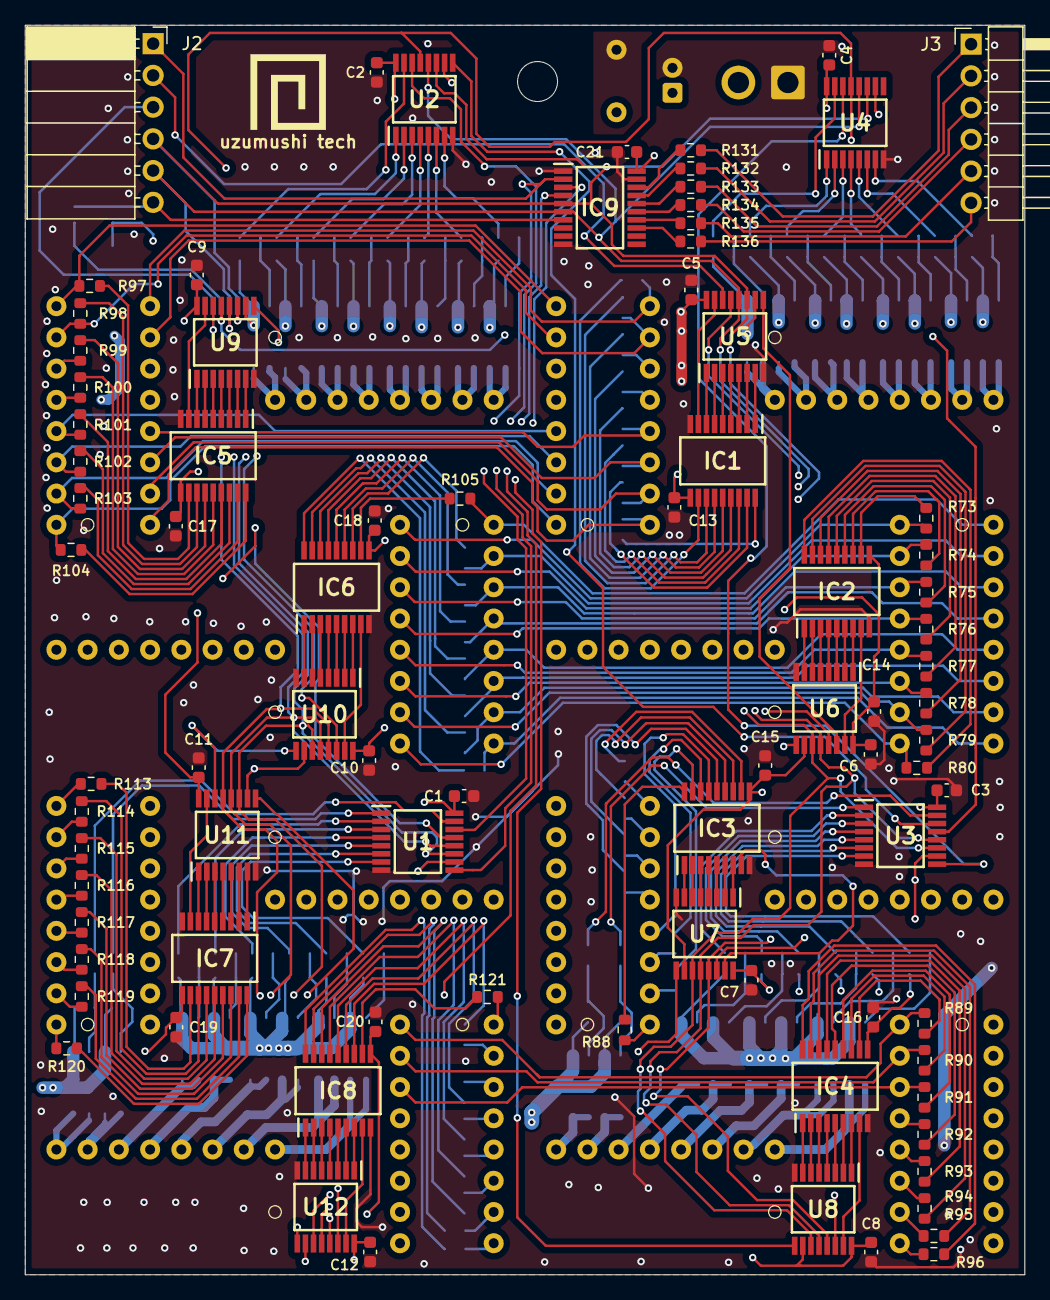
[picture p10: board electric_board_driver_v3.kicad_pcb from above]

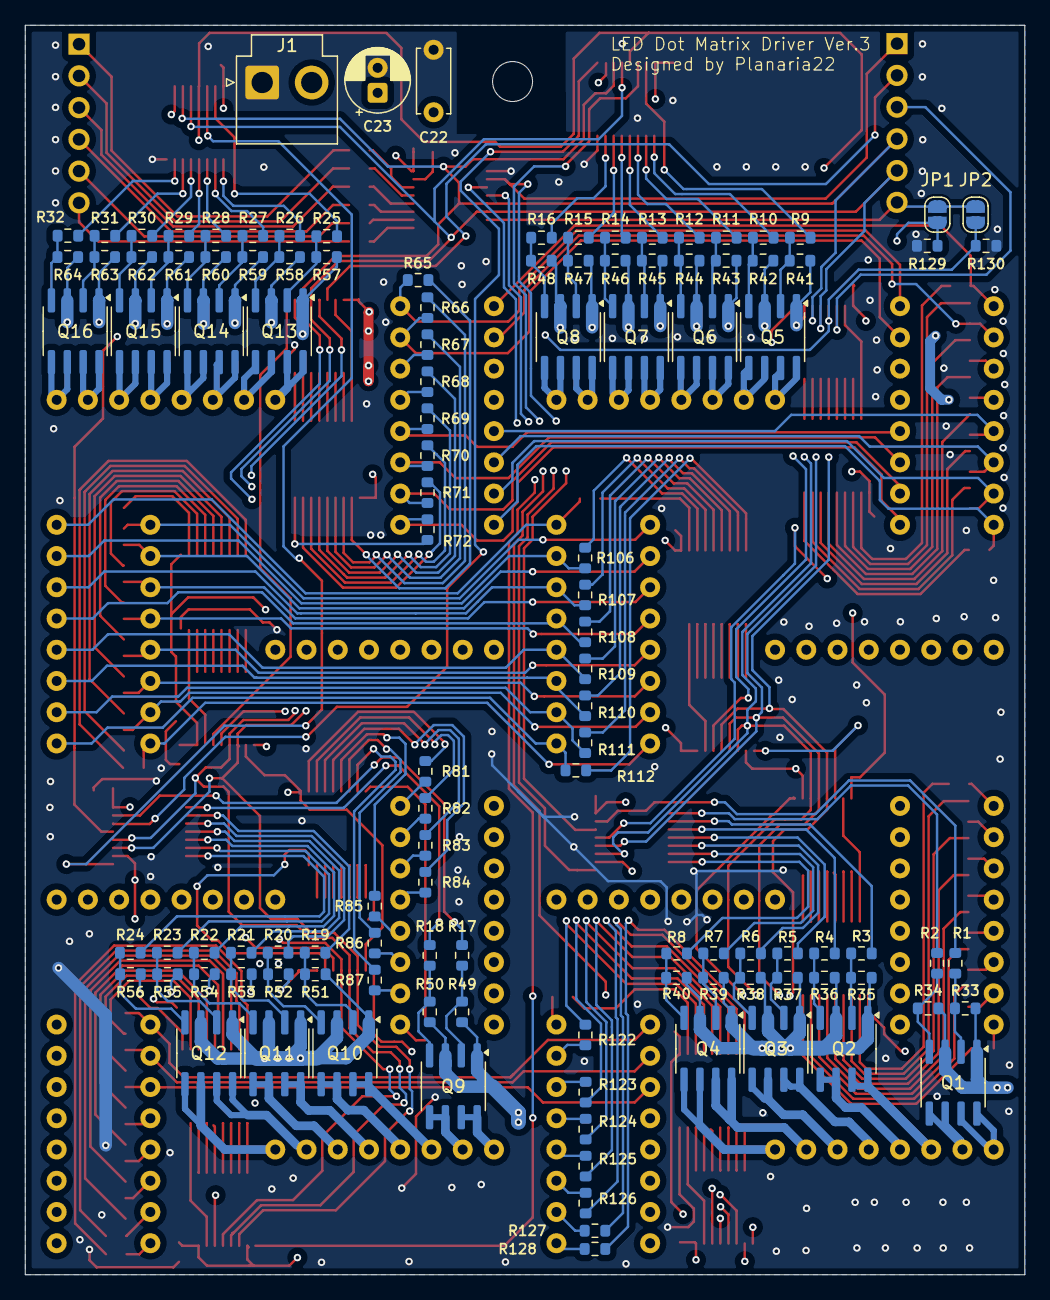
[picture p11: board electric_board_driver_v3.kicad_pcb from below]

Board: 4 copper layers, 80.0 x 100.0 mm, 206 parts (116 on the bottom side), 321 nets.

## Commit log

2026-10-05 upload PCB and Schematic
    [electric_board_driver_v3.kicad_pcb, electric_board_driver_v3.kicad_sch]
2026-10-05 add schematic pdf
    [electric_board_driver_v3.kicad_sch]
2026-11-03 modified main and add controller schematic
